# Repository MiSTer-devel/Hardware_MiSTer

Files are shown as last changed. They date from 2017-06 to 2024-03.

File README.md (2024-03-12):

# Hardware addons for MiSTer

### [I/O Board](https://github.com/MiSTer-devel/Hardware_MiSTer/tree/master/Addons/IOBoard), [AV Board](https://github.com/MiSTer-devel/Hardware_MiSTer/tree/master/Addons/AVBoard), 
I/O Board provides digital audio output, buttons, LEDs, user port, and VGA connector. It also supports secondary SDRAM (experimental).
With additional AV Board it adds VGA and analog audio output (but loses secondary SDRAM feature). I/O Board also provides external buttons and LEDs connectors for easier integration in various cases.

### [RTC daughter board](https://github.com/MiSTer-devel/Hardware_MiSTer/tree/master/Addons/RTC)
This board provides real time clock. It's plugged into LTC connector.

### [SDR SDRAM daughter board](https://github.com/MiSTer-devel/Hardware_MiSTer/tree/master/Addons/SDRAM_xsds)
This board provides 128MB of SDR SDRAM memory for cores requiring a large (>512KB) memory. Although DE10-nano has DDR3 RAM, it has big
latency and cannot fit into timings of retro EDO DRAM. So, if core quires precise memory timings, then DDR3 cannot be used.
Although some cores aren't requiring this board, still many cores need it.
Thus **SDRAM board is required**.

### [USB Hub daughter board](https://github.com/MiSTer-devel/Hardware_MiSTer/tree/master/Addons/USBHub)
This board provides 7-port USB hub for convenient devices connections. This is optional but recommended board.

### [MT32-Pi board](https://github.com/MiSTer-devel/Hardware_MiSTer/tree/master/Addons/MT32PiHat)
This boards adds external MIDI emulation plugged into user port. [Smaller version](https://github.com/MiSTer-devel/Hardware_MiSTer/tree/master/Addons/MT32PiHat_LT) is also available.

### [PiTop boards](https://github.com/MiSTer-devel/Hardware_MiSTer/tree/master/Addons)
The set of boards with PiTop in name are made to fit MiSTer into Pi-Top case. Note: it's for Pi-Top v1(original) case only. Pi-Top v2 case has completely different placements and conections and therefore is not compatible.

## Notes
You need to use Altium Designer v21.0 (or later) in order to view the source files. For convenience, [gerber files (*.zip)](https://github.com/MiSTer-devel/Hardware_MiSTer/tree/master/releases) are also included
and ready to submit to PCB manufacturer.

Some quick notes:
* **There are no notches/dents on 40pin connectors, so pay attention how you plug the daughter boards!** It's easy to plug it backward or shifted - **this may damage DE10-nano board**. Make sure PIN1 on one board is matched to PIN1 on other board. You may refer to pictures in images directory.
* It's preferred to order 1.6mm PCB thickness. I've tried 0.8mm and found no improvements in any aspect.
Thinner PCB are harder to handle and more fragile.
* SDRAM uses AS4C32M16SB-7TCN (64MB chip). Use [Memtest](https://github.com/MiSTer-devel/MemTest_MiSTer/tree/master/releases) utility to check the quality of SDRAM board.
* Every board has PDF file with schematic and PCB outlook, so you don't need any special application if you are not going to edit the files.
* Some images of boards can be found [here](https://github.com/MiSTer-devel/Hardware_MiSTer/tree/master/images)

### Options for PCB ordering:
* Board type: Single pieces
* Different Design in Panel: 1
* Quantity: usually 10. See the final price after change the quantity.
* 2/4 layers
* Material: any FR-4
* Thickness: 1.6mm
* Solder mask/Silkscreen colors: any you like if price the same.
* Min Track/Spacing: 6/6mil or less
* Min Hole Size: 0.3mm or less
* Via Process: Tenting vias
* Gold fingers: No
* Finished Copper: 1oz or more
* Surface Finish - HASL with lead. Some manufacturers provide ENIG (immersion gold) for free, but i don't suggest it as it's harder to solder than HASL (pre-soldered finish). "With lead" means lower soldering temperature. "Lead free" will require higher temperature for soldering.

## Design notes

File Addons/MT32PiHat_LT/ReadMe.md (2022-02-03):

# MT32-pi Lite boards set

* MT32Pi_lite - simplified MT32-pi board for Raspberry PI Zero 2
* MT32Pi_lite_Top - single sided aluminum 1.6mm PCB used as heat sink. This board needs spacers about ~1.5mm for screws. It needs thermal tape of 3mm thickness for main chip.
* MT32Pi_lite_Top_Cut - same as above but with cut places to mount it on top without spacers. It needs 2mm thick thermal tape.

As an option: you may mount both MT32Pi_lite_Top_Cut and MT32Pi_lite_Top, so Cut version will be used as a spacer and additional heat dissipation.

MT32Pi_lite board is soldered directly to RPI with short pins without connector. No need to solder all 34 pins. Soldering outlined pins is enough.

Whole pancake is plugged directly into USER I/O port as a side cart.

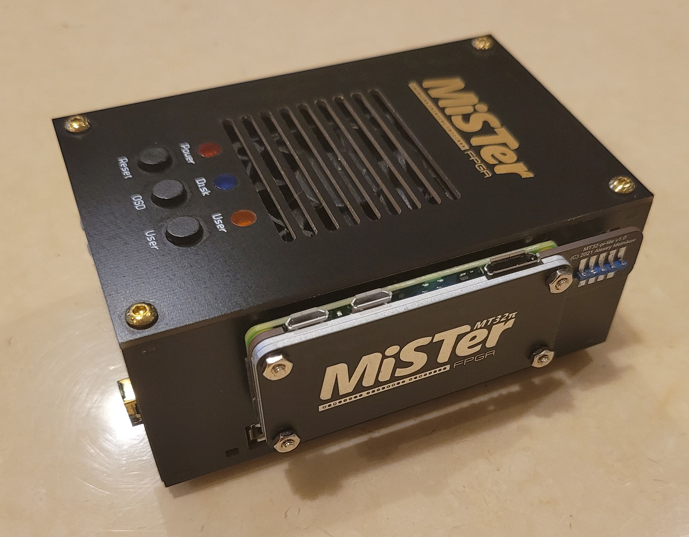
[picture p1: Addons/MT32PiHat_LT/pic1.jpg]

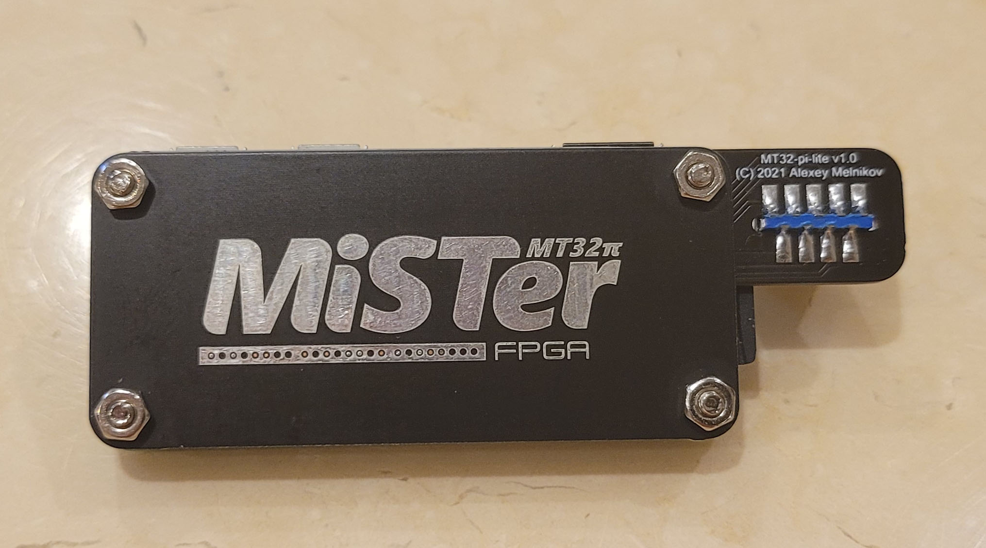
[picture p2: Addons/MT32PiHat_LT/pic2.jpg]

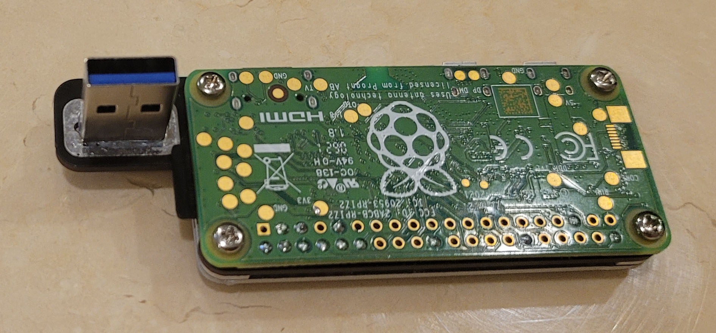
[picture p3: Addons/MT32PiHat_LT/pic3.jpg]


It needs a special USB3.0 connector:
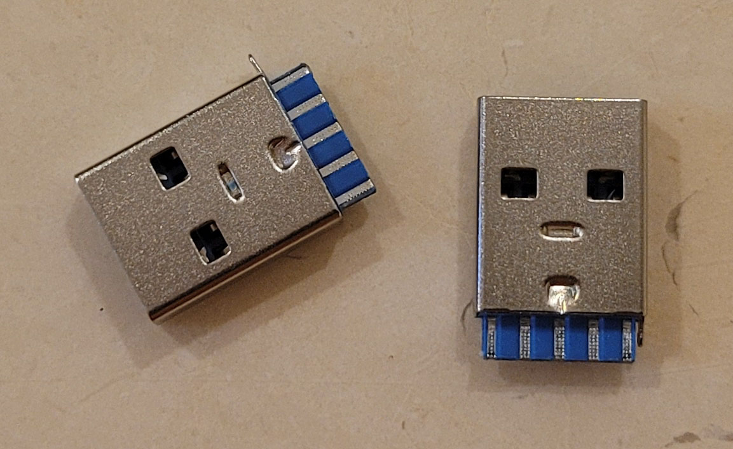
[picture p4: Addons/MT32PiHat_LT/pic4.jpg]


It can be found on Aliexpress and Amazon.

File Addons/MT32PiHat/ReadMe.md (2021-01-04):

# MT32-pi interface board

There are several simplified ways to connect MT32-pi without board at all. LCD and Buttons aren't required. 
You can see LCD overlay on MiSTer screen and change the mode from OSD. So basically you can wire USB-A connector to 40pin Raspberry Pi connector.

### Connection options:
* Basic MIDI connection: USB 2.0 connector is enough in this mode. Connect GND, VCC and TXD pins only. Since you cannot see LCD on MiSTer in this mode and cannot control MT32-pi, it's better to have LCD on device and buttons to control. In this mode you can connect basically any MIDI sequencer (not only MT32-pi).
* Audio-less connection. You need to connect GND, VCC, TXD, SDA, SCL pins. In this mode you will see LCD overlay and can control MT32-pi from OSD. Audio won't be mixed in MiSTer so you will need to use either I2S DAC on MT32-pi or 3.5mm jack on Raspberry Pi.
* You can use Main board but solder only 40pin connector and one USB. Useful for embedded designs.

### Notes
* There are 2 types of USB-A <-> USB-A. Straight one with all wires connected the same way on both sides. Crossed one where TX wires from one end connected to RX wires. No special notes required for crossed cables, they are pretty common and compatible with all MiSTer I/O boards. With straight cable you need a recent version of I/O board where IO6 pin is available and configured as IO pin (not 3.3V supply) otherwise 3.3V will go to output RPi pin. This may dammage the RPi. Resistor (R1) with 100 Ohm is used on board to avoid this colission and prevent RPi from damage.

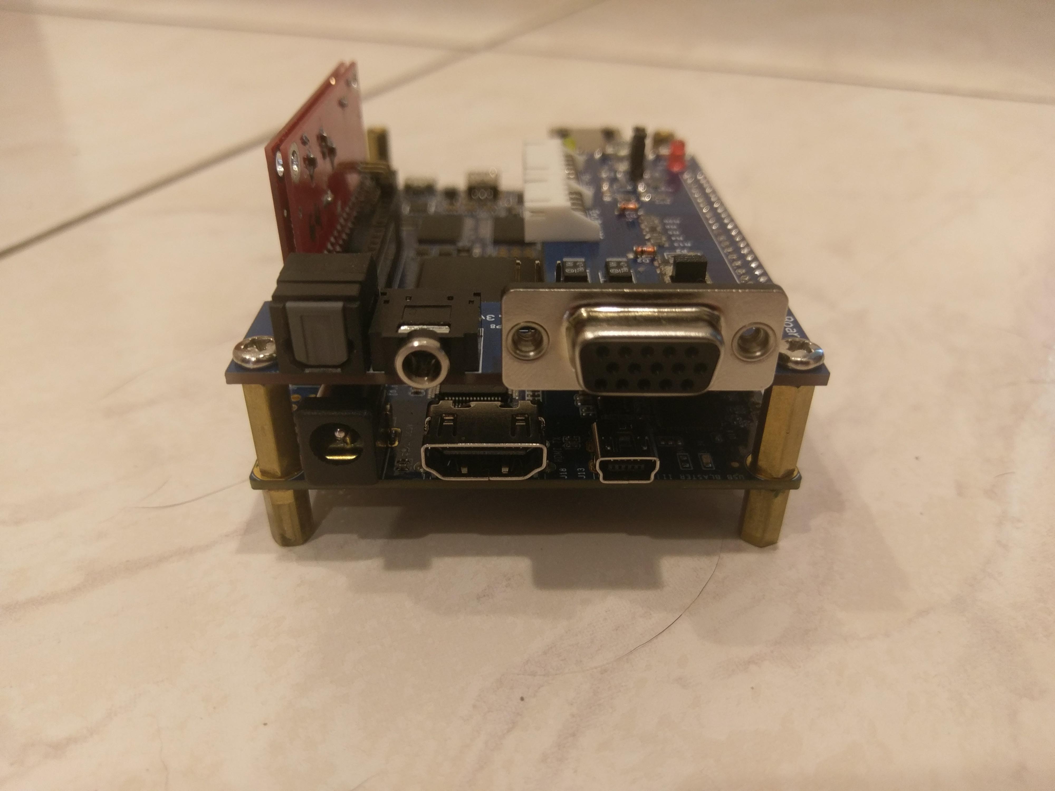
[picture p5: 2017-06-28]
images/MiSTer_2.jpg

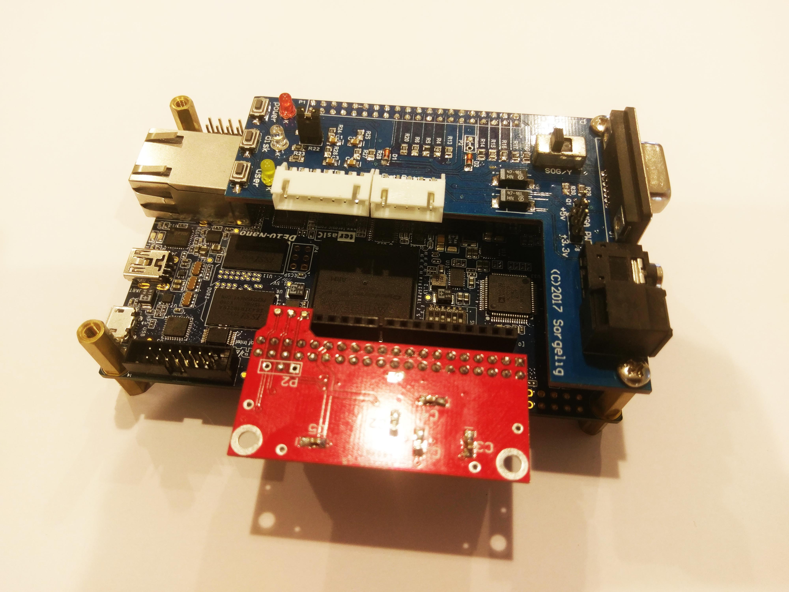
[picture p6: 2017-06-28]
images/MiSTer_SDRAM_horiz.jpg

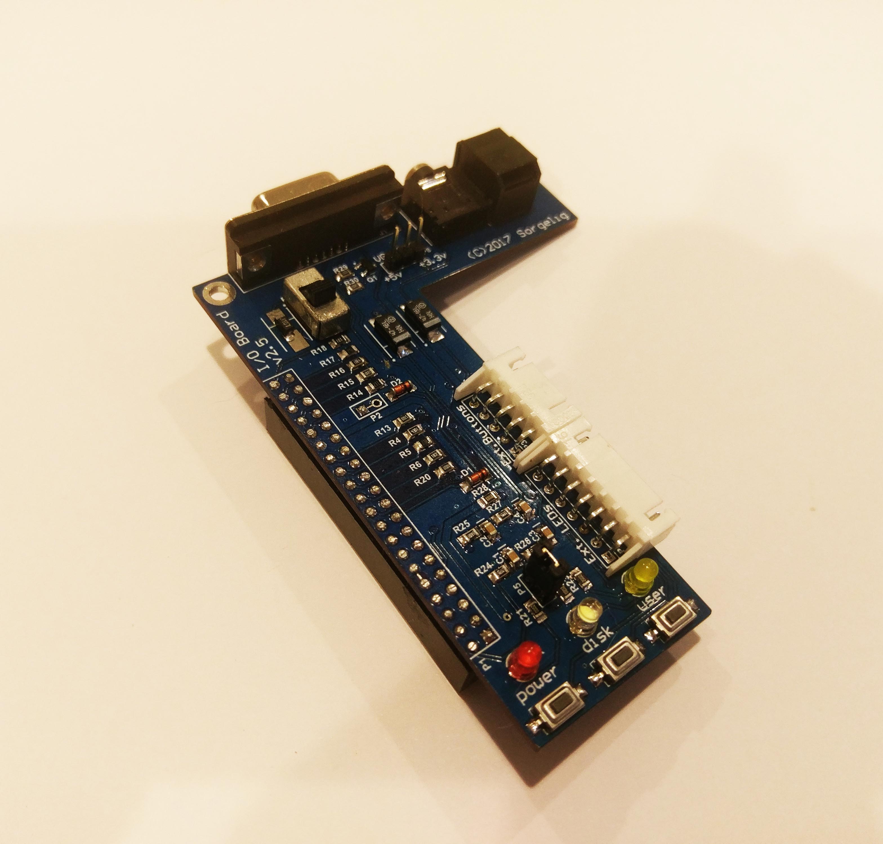
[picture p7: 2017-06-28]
images/IOBoard.jpg

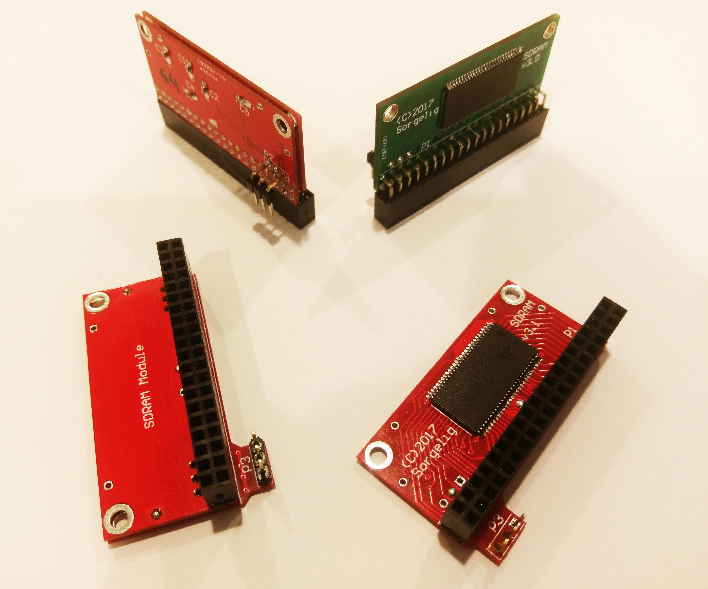
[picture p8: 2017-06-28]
images/SDRAM_board.jpg

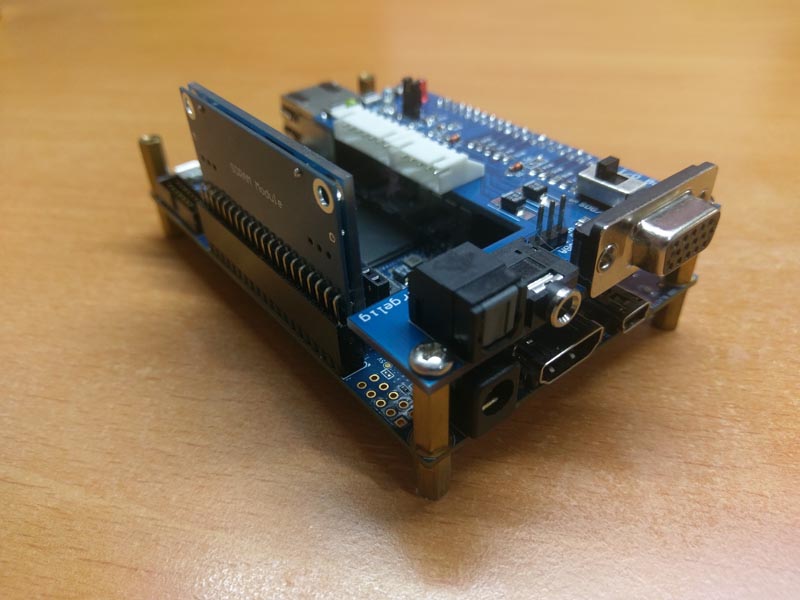
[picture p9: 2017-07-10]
images/MiSTer_AIO_SDRAM.jpg

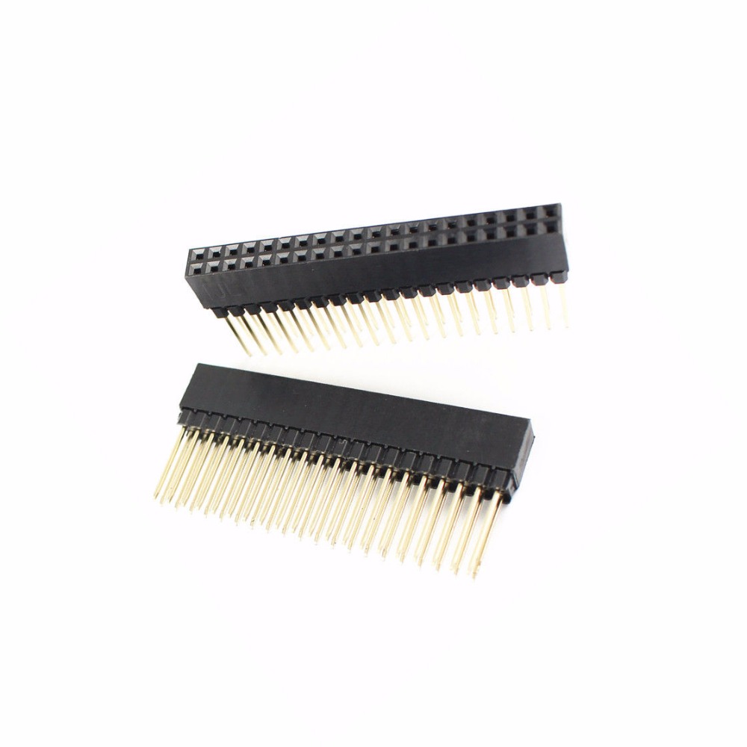
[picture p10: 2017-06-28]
images/header_2.54mm_Pitch-2x20_Pin-Female-Double_Row-Long_Pin.jpg

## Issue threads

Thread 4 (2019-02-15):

IO Board ESD Protection

zerohimself, 2019-02-15:
So, last week I damaged the FPGA on my DE10 board by accidently supplying a ESD shock to the button housing of the OSD menu on the IO board. The shock killed both GPIO pins for the OSD and USER buttons. I was using the IO board 5.5

I'm wonder if there is any protection that we can put in, maybe a diode somewhere?
Maybe this is a user issue, as we take that risk by using a bare PCB not in a case, but I figured I should report the issue and at least make a suggestion for someone who is more knowledgeable than me.

sorgelig, 2019-02-15:
I don't think it's possible to do anything against it. If you got high static charge on your body due to specific wear or something on surface where you walk, then discharge will be too high to protect 3V electronic device.
You need the case where buttons will be protected by thick plastic.
It's better to find the source of charge, put some grounded line which you will touch before touching electronic devices.

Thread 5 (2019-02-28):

'Order the boards' link leads to no project on PCBWay

dine909, 2019-02-28:
The embedded hyperlink in README.md leads to a dead-end.

https://www.pcbway.com/project/member/shareproject/?bmbid=43024

sorgelig, 2019-02-28:
PCBWay changed the link.
I've fixed it.
Thanks for info!

Closed 2019-02-28.

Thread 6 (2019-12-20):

problem with via tenting with SDRAM XSD v2.5

thioroup8, 2019-12-20:
Hi

I recently contact JLCPCB service to produce PCBs for SDRAM XSD v2.5. I used this gerber file: https://github.com/MiSTer-devel/Hardware_MiSTer/blob/master/releases/sdram_xsd_2.5.zip

Unfortunately, they sent me an answer containing question and I am unable to reply to them because of lack of knowledge.
Please find below a copy of their message.

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

Please help me to write appropriate answer to JLCPCB service.

Thank you for your attention.

sorgelig, 2019-12-20:
Time after time JLCPCB start to send stupid questions. This gerber file made many times by them without any questions.
Here also quite stupid ask from them. It's obvious the vias on pads are opened while without pads they are tented. 2 columns of holes in the middles are holes for THT connector, not vias.
Tell them to transfer approval to other more professional person.

thioroup8, 2019-12-20:
Thank you so much for your quick reply.
I already ordered all electronic parts from mouser and I was afraid to be unable to solder my own PCB due to JLCPCB manufacturer :(
I hope they understand my answer I will send to them following your instructions.
I understand it is not an issue in your design and so sorry to place this message in the wrong place...

thioroup8, 2019-12-20:
oups I clicked on wrong button.

thioroup8, 2020-07-13:
Hi

I am back again with my first try to solder a SDRAM board for my MiSTer.
Sadly I have some issues :( My memory board is not recognized by memtest utility.
So, I double check with my microscope and my multimeter. All seems correct.
So, I check another PCB without any component solder on it.
My multimeter detects unexpected connections: I mean, I am surprised to find thoses connections because I do not see them on gerber files. Please have a look on attached picture: unexpected connections in red.

What do you think about thoses connections? Is there any issue during PCB manufacturing?
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

sorgelig, 2020-07-13:
I don't see what unexpected there. GND to GND, VCC to VCC. Looks fine to me. Board has 4 layers, not 2.
I can't tell about manufacturing problem - it depends on specific manufacturer.

thioroup8, 2020-07-13:
On U2 chip, pin 54 is VSS
On U1 chip, pin 37 is CKE and pin 28 is VSS
So I do not understand "GND to GND"?
By simply looking at GTL, G1, G2 and GBL, it is difficult for me to deduce from these 4 gerber files the existence of those 3 connections (in red). I probably misunderstand gerber files: I need to improve my knowledge on this topic.

My SDRAM board is faulty and I do not know why:
- bad solders
- pcb issue
- component faulty
- ...

sorgelig, 2020-07-13:
VCC - is power, 3.3V
VSS - is GND.
CKE is connected to VCC - correct.
Even on your pic you clearly can see VSS pins are connected to ground.
You can check connections using schematics.
I don't have more files than i upload.

thioroup8, 2020-07-13:
Well
I made a lot of checks on an empty PCB and I think PCBs are correct.
I suspect I used an excessive soldering temperature of 350 °C and I killed one or several components because datasheets recommend a temperature between 235 °C and 260 °C.
Stupid mistake to learn :(

david-cash, 2024-07-10:
I already ordered all electronic parts from [OVAGA](https://www.ovaga.com/) and I was afraid to be unable to solder my own PCB due to JLCPCB manufacturer :(

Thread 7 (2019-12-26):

Q: Is it possible to use only one bank of the SDRAM XSD v2.5

vidarw, 2019-12-26:
Hi,
Thanks to everyone for designing and creating this well documented DYI-system.

I just realized the relatively high prices of the 512M Alliance Memory SD modules.
Is it possible to mount only one chip in the dual PCB and add the second memory chip at a later time?

sorgelig, 2019-12-26:
You can try. It may have slightly different timings and some cores may misbehave.

Closed 2022-11-27.

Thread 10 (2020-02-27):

The MiSTer I/O board does not output the proper voltages on the DB15 connector to allow for automated AV features over SCART

mathieulh, 2020-02-27:
The I/O board should be revised to add voltage to SCART PINs 8; 18 and 16
so it gets on spec and allows for automated AV selection

This would mean using unused pins on the DB15 connector for voltages and modifying the MiST cables.

This would allow automated AV features (assuming you switch to an updated MiST SCART cable) as per official SCART specifications

This way MiSTer could:
* Automatically turn on your TV
* Automatically switch your TV set to the AV channel on sets that support it (most sold in Europe since the mid 90s)
* Force force the use of specific signals over the same RGB cable (for instance switch from RGB to composite without changing the cable)
* Force 4:3 or Widescren aspects ratio (should someone ever need that)

More details regarding those specifications and features are available here:

http://forum.arcadecontrols.com/index.php/topic,77370.msg806492.html#msg806492

and

http://forum.arcadecontrols.com/index.php/topic,77370.msg830465.html#msg830465

sorgelig, 2020-02-27:
Sorry, it's out of MiSTer scope.
VGA connector has option "VGA_PWR through pin 9. It may output 3.3V or 5V. If you want other voltages, then you need to add external step-up DC-DC converter.

Closed 2022-11-27.

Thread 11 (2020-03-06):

The MiSTer I/O board has serious issues with brightness levels when connected to a VGA monitor

mathieulh, 2020-03-06:
The MiSTer I/O board has serious issues with brightness levels when connected to a VGA monitor

When I plug a shilded coaxial VGA cable (ie, the best quality you can get) to the dsub 15 output from the IO board to my CRT VGA monitors (I tested 2 different ones) the brightness is very dim
almost as if you did not have adequate impedance or power output.

If I connect the exact same cable (and monitors) over direct video using the same MiSTer configuration the image looks great with no brightness issues whatsoever.

This appears to be hardware issue related to the I/O board itself.

sorgelig, 2020-03-07:
It must be very specific to your setup/monitor.
Usually VGA output provides good video. I have tried many monitors - no problem with brightness. Anyway, if more strong signal is needed then it will require additional amplifiers. It won't happen in I/O board as there is no place on board and 5V power will not be enough for analog amplifiers.
Use Direct Video - it provides more bits per color and better audio DAC.

mathieulh, 2020-03-07:
Hum... I am having the issue on both my CRT monitors, a Sony Trinitron CPD-200GST and a Compaq P1220 (Mitsubishi Diamondpro 2060U rebrand), the only thing I have not tried yet is swapping the I/O board as I do not own another at this point. I also tried different cables.

sorgelig, 2020-03-07:
May be wrong video DAC resistors are used on I/O board.

twinkytwonka, 2020-06-14:
> Hum... I am having the issue on both my CRT monitors, a Sony Trinitron CPD-200GST and a Compaq P1220 (Mitsubishi Diamondpro 2060U rebrand), the only thing I have not tried yet is swapping the I/O board as I do not own another at this point. I also tried different cables.

If it's a V6 or 6.1 io board then what resistor array pairs did you use? Your choice has a significant effect on brightness levels . If you're using a 5.7 board then double check components with the schematic

Closed 2022-11-27.

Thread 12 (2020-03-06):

Pulsing LEDs on powerup, nothing else happening!

Galbi3000, 2020-03-06:
I've not used my MiSTer for a few months (been busy PC gaming instead of retro). It's just been sitting on my desk in all the time unpowered with the same SD card in since the last time I used it, not taken it out to update or make any changes.
Today I decided to boot it up again as I got some new ROMS I wanted to try out, I switched the MiSTer on and nothing happens. Well, nothing that should happen.

What I am getting instead of the MiSTer bootup sequence on my TV is no signal and the addon board pulsing the red and yellow LEDs (labled POWER and USER respectively). The smaller red LED is just on.
Under the addon IO board I see the green LEDs beside the ethernet port also pulsing the first and fifth LEDs.

What is going on? Like I said, the last time I booted it up it worked fine and it's just been sitting there unpowered until today.

Here is a GIF to show what the LEDs are doing:

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

sorgelig, 2020-03-06:
Please use forum for discussion. Github is for specific issues.

Galbi3000, 2020-03-07:
How is this not an issue? The thing is not working and I do not know why!

sorgelig, 2020-03-07:
LEDs flashing is correct.
post your problem here:  http://www.atari-forum.com/viewtopic.php?f=117&t=34710

Galbi3000, 2020-03-07:
Well, if the LEDs flashing is correct, that still leaves the fact I have a black screen on my TV, there is still an issue of the device not functioning as it should! It is in my description of what is wrong and in the issue title "nothing else happening!". You are always so quick to just dismiss an issue it seems. I have started actively pointing this out on YouTube videos talking about the MiSTer, an otherwise good product let down by poor support. Good bye.

sorgelig, 2020-03-08:
Ask those where you've bought the product. I didn't sell you anything.
This is my hobby and i do this for free.
Please leave and don't come back again!

RetroShopPT, 2020-03-08:
> Well, if the LEDs flashing is correct, that still leaves the fact I have a black screen on my TV, there is still an issue of the device not functioning as it should! It is in my description of what is wrong and in the issue title "nothing else happening!". You are always so quick to just dismiss an issue it seems. I have started actively pointing this out on YouTube videos talking about the MiSTer, an otherwise good product let down by poor support. Good bye.

Hi, look like a bad sdcard update and not hardware issue. Anyway, from photo, look like a board sold by me, and if you have any problem with hardware, just send me a message on Facebook or on my site.

Closed 2020-03-07.

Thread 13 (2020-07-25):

MiSTer I/O board detection? Custom VGA resistor ladder detects no signal on pins

JohnBFrm, 2020-07-25:
Hi,

I'm working on building my own resistor ladder for outputting various analog video signals as per the design of the "VGA" output (knowing it's not an actual VGA output) on the IO boards.

However, I am unable to measure a signal on the pins. It seems to just be a fixed voltage, flatlining my oscilloscope.

Does MiSTer require some sort of pin pull-up or down in order to detect that an IO board is attached and use the GPIO pins for their intended function?

JohnBFrm, 2020-07-26:
As this  is not an issue with a board per se, I'm going to close the issue with the following comment:

It's not explicitly stated in the board documentation, but pin 10 needs to be connected to ground, works fine with pin 12 and pin 30 as per the IO board schematics. This makes sure analog video output is enabled.

Closed 2020-07-26.

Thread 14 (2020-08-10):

Supply a proper BOM and/or Altium files in ASCII format

fade0ff, 2020-08-10:
The Wiki typically describes old versions of most addon boards and there doesn't seem to be a BOM, so it's a bit of a drag to find out which exact components are needed. Also it would help if the design files (schematic/layout) would be stored in Altium ASCII format so there would be at least a chance that more affordable EDA tools could import them.

iCityWork, 2020-12-02:
I second this! I would love to see a BOM for all the latest versions since I have a Mac I can not use the design software this was done in.

birdybro, 2021-04-14:
Third'ed. Definitely would love to see actual general BOM's for these pieces of hardware someday.

DanielBarie, 2021-09-28:
Upvote!

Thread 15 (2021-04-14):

Request: STEP or STL files for each board for easier CAD design of accessories.

birdybro, 2021-04-14:
I would love if I could load a STEP or STL file of the boards and their components in one of the many free CAD programs out there to begin designing 3d printed cases and accessories. Unfortunately this currently requires extremely expensive premium software to even export these, and there are tools online like altium2kicad but they are not very functional. I realize that moving to open source PCB design tools is undesirable however can some of the paywall-locked features like STEP/STL export from the Altium format be at least provided for us here?

Thank you!

KhalidHisham, 2021-04-19:
you mean like this?
[sdram_xsd 3D-model.zip](https://github.com/MiSTer-devel/Hardware_MiSTer/files/6337187/sdram_xsd.3D-model.zip)

I am new to gethub so I am not sure how to upload the files to the repo otherwise I can help.

\K

KhalidHisham, 2021-04-20:
Thanks, I will do it as soon as I can.
Perhaps it will be cleaner to put all the step files in one folder?

birdybro, 2021-04-20:
Maybe. I usually try to match the folder structure that the repository
already has to make it more agreeable to the maintainer of that repo.

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

KhalidHisham, 2021-04-20:
Ok so I generated everything but it seems i can't add the files using GitHub desktop. for some reason no changes are shown when I simply put the files in their respective places. Is there a way to fix?

birdybro, 2021-04-21:
Looks like it worked!

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

Next you have to submit the pull request.

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

:)

KhalidHisham, 2021-04-21:
That was quite detailed,
Thanks :)

birdybro, 2021-04-21:
Glad to help. Welcome to GitHub! 👍🏻

KhalidHisham, 2021-04-22:
Thank you. It is done now.

I found out the problem I had with the gitHub desktop. It seems that the all STEP files are placed on ignore list in the repository configuration. So I decided to zip all the files before adding them to their respective folders and it worked.

sorgelig, 2021-04-23:
it's on repo now

Closed 2021-04-23.

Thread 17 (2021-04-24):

SDRAM XSDS v2.9 decoupling issues

prrole, 2021-04-24:
Pin 37 CKE is decoupled, while pin 1&3 VCC share a capacitor.  I assume this is a routing mistake as all 3 pins are labeled VCC.

74LVC1G04 could probably benefit from a decoupling capacitor as well.

sorgelig, 2021-04-24:
pins 1&3 are very close to each other and have large polygon connected to both, so i don't think there will be any noticeable benefit for that.
Pin 37 has capacitor not as CKE but as distributed capacitance since it's far from other capacitors.
For LVC1G04 - probably can connect its VCC to upper polygon and share the cap nearby. I will think about it if i will update the design

Closed 2022-11-27.

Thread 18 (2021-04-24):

SDRAM XSDS v2.9 missing part number

prrole, 2021-04-24:
There is no part number for P1 2x20 SMD connector in schematics or pcb file.  The 3D model shows a connector that is not common or easy to source, so a part number/source is needed to build this board.

sorgelig, 2021-04-24:
Because it's common connector without specific part number.
you can find it on Aliexpress or eBay.
you may order this one:
http://www.townes.com.tw/product_detail/land-ctop-2/index.php?Product_SN=68153

Closed 2022-11-27.

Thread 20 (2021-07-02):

SDRAM XSDS v2.9 has a strange solder pad.

type78, 2021-07-02:
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

There's a strange small solder pad on v2.9 SDRAM PCB. (please see the picture I attached.)
Is it intended?  If it is, what's the purpse of this small pad?

sorgelig, 2021-07-02:
it's an option. You may opt out LDO and solder that pad with nearby pin together to get 3.3V from de10-nano

Closed 2021-07-02.

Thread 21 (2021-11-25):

Provide viewable static files without requiring software install

aeberbach, 2021-11-25:
It would be great to be able to look at a schematic without having to install PCB software. Altium?

aeberbach, 2021-11-25:
Found them in releases folder

Closed 2021-11-25.

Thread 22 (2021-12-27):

Help with usb board

sonik-br, 2021-12-27:
Hi,

My USB board is busted. The component over the U2a (NCP380LSNAJAAT1G) is burned and I can't find another to buy.
There's any equivalent component that will work?

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

sorgelig, 2021-12-28:
option #1: you may disable VBUS control, so you won't need this chip. USB devices will have permanent 5V supply from main power. Refer to schematics and notes there.
option #2: there are no equivalents. There is only version for uDFN6 case of the same chip which may hold slightly higher current than busted TSOP6 version.

sonik-br, 2021-12-28:
Thanks for the answer.

I'm a layman in electronics .

What's the purpose of VBUS? If I get it right, it's to power on/off the usb hub in sync with mister's main board?

For option 1 I can just bridge the JP3? JP1 too?
It will drain power from the mister's usb or from external psu?

sorgelig, 2021-12-29:
> What's the purpose of VBUS? If I get it right, it's to power on/off the usb hub in sync with mister's main board?

it allows USB host controller to turn power on/off of USB devices.

> For option 1 I can just bridge the JP3? JP1 too?

Short JP1. JP3 doesn't matter.

> It will drain power from the mister's usb or from external psu?

It will drain power from the same source as with VBUS control.

sonik-br, 2022-02-05:
My board is dead. Even without VBUS. Power works but no data.
I've got a new one :)

Closed 2022-02-05.

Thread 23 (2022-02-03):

Solderless MT32Pi_Lite using pogo pins

tmznix, 2022-02-03:
Is it possible to modify this board to use pogo pins instead of soldering ?

Something like this: (examples)

https://thepihut.com/products/pogo-a-go-go-solderless-gpio-pogo-pins

Or this:
https://pinout.xyz/pinout/zero4u#

And the last one ( I promise :) )
https://www.kickstarter.com/projects/pico-learber-board/notixed-turn-your-pi-zero-to-usb-device

Cheers!

sorgelig, 2022-02-04:
From PCB point of view, no modifications are need. Since pins are too high, you will need to place MT32Pi_Lite under the RPi so USB3.0 plug will be able to fully inserted. Overall construction will be very thick and bulky. If you like this then use it. Original idea was to eliminate connectors and make construction as slim as possible.

rataweb, 2022-03-02:
Hi,
It's a good idea.
Please, Could you upload Altium pcb files in ASCII format? I'm using Eagle and it's the only way to import Altium files. I'll try to modify by myself.

Many thanks
Shark

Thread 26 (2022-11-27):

[Feature Request] Hardware_MiSTer/io_brd_6.2 with dedicated DAC circuit

ArcadeTV, 2022-11-27:
I use io_brd_6.1 on my MiSTer Setup with [this external DAC](https://amzn.eu/d/gATQUuJ) for better audio.

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

To minimize the need for cables and power supplies I had the idea to merge the DAC's circuit into the io board. Before I start creating a pcb for modding io_brd_6.1 I wanted to ask if this may eventually be added to io_brd_6.2. By merging the circuit into the io brd R6 (75R), the AMS1117 regultor and its components and the coax-parts become obsolete. [Here](https://www.dropbox.com/scl/fo/4myo1c3tk06i6u13dm5p3/h?dl=0&rlkey=h2cjf12vrrlcghgtq57sm88s8) is my Dropbox folder containing my scans and datasheets.

I don't know or have Altium, so I'd like to know if it would be possible to export the io_brd_6.1 to eagle or if the DAC circuit could be included in the next version of the pcb, maybe with an addional switch to toggle between native audio and DAC output.

If this may be rejected, I plan to create an addon-pcb that may be positioned here and using the existing pads:

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

---

For prerequisites I stripped the DAC and drew its schematic:

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

sorgelig, 2022-11-27:
I suggest to make an addon board using I2S header from I/O Board, so it will follow modular structure of MiSTer. I use it as well for some my embedded MiSTers. It will eliminate CS8416 as well. Just need to find I2S DAC which can work without MCLK. Current I/O Board has no free space for such circuit, so embedding it to board will require a denser routing and smaller components which i don't want to do. I want to make it DIY friendly.

If you will do an addon board then may be it would be better to make a tiny board which will plug directly to that i2s connector and use 3.5mm jack on top of existing one. Just thoughts..

Thinking more about this: most modern high-end amplifiers have either optical or coaxial input which is anyway better than analog. Your board is mostly for integrating into some arcade cabinet where such amplifier is not available. Thus using original external converter should be fine already. If your amplifier has no digital input, then you may place this converter near your amplifier and hide somewhere there, so for MiSTer you will need only thin optical cable.
HDMI btw, has no such issue as it delivers digital audio. In direct video mode you can use HDMI-VGA converter with audio output.
So, basically there are many options for better audio are available.

sorgelig, 2022-11-27:
btw, i even not sure if integrated converter on I/O board will have enough noise over power/gnd isolation. Analog part should be well isolated which separate board with separate power supply does.

sorgelig, 2022-11-27:
not sure your original intention of using this converter.
In case if you use HDMI output and simply want to connect some small stereo speakers, then this converter probably will be more suitable:
https://www.amazon.com/Optical-ROOFULL-Extractor-Splitter-Converter/dp/B01LL5RI3Y

ArcadeTV, 2022-11-27:
Thank you very much for taking the time to answer, this is very much appreciated.
The motivation for this is to NOT have extra external hardware and power supply. The device works great, but I'd love to have it inside the MiSTer. I'm not a professional, so any hint about best-practise and isolation is great. Maybe additional coils or EMI-filters could cut the noise?

This is what I had in mind, piggyback an add-on-pcb under the I2S and VGA-PWR headers, so they can be installed back and stay functional. For L and R audio-lines, either the traces could be cut or C11 and C12 could be removed and DAC-output connected to their pads.

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

This is a mockup of what it could look like, all the parts are already present.
This is not as modular as I'd love to make it, but if it works it would be beneficial for me.
Since I use CRT's only, I never connect HDMI.

retrorepair, 2022-11-28:
It seems to me all you would need there is a pin header where you have the pads currently and maybe a dip switch/jumper block to select built in audio and I2S on the jack output. The wouldn't impact the IO board's design at all and then everyone's happy?

It has to be said, using those cheap Amazon DACs gives a vastly superior analog audio output than what's built in. I'm not much of an audiophile but it's a huge step up. Eradicates the pops on core change too.

ArcadeTV, 2022-11-28:
Indeed, that would solve the problem. I did some routing in the meantime.

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

retrorepair, 2022-11-28:
Looking good.

Rather than cut the board traces, you could always remove the two large caps under the IO and hijack the audio output from the two vias leading to them. I think your board would need to extend to the far one though and I believe your caps/resistor may currently be in the way of the other.

I always find soldering to cut traces a bit hacky and often leads to poor connections.

The other alternative would be to cut the two traces leading to the I2C header before then hit RN17 and the top side traces to the GPIO, then either run jumper wires from the I2C to the audio jack or maybe even a nice QSB to keep it somewhat tidy? Hijacking those now spare pins of course with your own audio outputs.

ArcadeTV, 2022-11-28:
> Rather than cut the board traces, you could always remove the two large caps under the IO and hijack the audio
Yes, I already wrote that C11 and C12 could be used for that.

> I think your board would need to extend to the far one though and I believe your caps/resistor may currently be in the way of the other.
I'm afraid there's zero space left to move anything around, so maybe the wires need to go from top to bottom - which would be ok when using a shileded cable

> You plan to add it as open source in the MiSTer GitHub?
I didn't plan ahead tbh, but I will create a repo with full source files once it's tested. I'm afraid, as sorgelig pointed out, there may be issues with ground loops and noise when run off the internal MiSTer power, so maybe coils and emi filters have to be added, but I have no experience with that.

n67t1cq, 2022-11-29:
It is good to implement PCM51002 into IOBOARD.

I've made i2s addon board for 6.1 last year. It works good.
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

ArcadeTV, 2022-11-29:
> PCM5102a

That's really cool and I wish I had know this existested before I started ;-)
Where can I get one? I've read that this IC is programmable - would you share some insights how it works?

ArcadeTV, 2022-12-01:
@n67t1cq could you share some insights?
Is it for sale or maybe even open source?

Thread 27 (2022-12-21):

Deprecate Secondary SD Card

thehughhefner, 2022-12-21:
Hi Sorg,
I think it is time to deprecate the secondary sd card. Today, it is not mandatory to use it, and cores that make use of it have other ways of loading ROMs. Wouldn't it be better to use another component instead? (Such as 24 bit rgb). It will also remove any user errors where they will be confused of the use of secondary sd card

sorgelig, 2022-12-21:
Actually analog output is kind of deprecate. Use direct video for 24bit VGA/TV output. Secondary GPIO connector will be re-purposed for extension to get more powerful CPU emulation (and may be other things).

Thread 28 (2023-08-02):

MT32Pi Top Gerbers broken

Shadowtrance, 2023-08-02:
Title.
It seems the gerbers for the MT32Pi Top piece are broken in some way.
When imported to jlcpcb this is the result (1).
And if you select the top or bottom after initial loading (2) you only see a corner of the pcb with a hole that isn't drilled out and not much else (3).
The main base board that actually matters _appears_ to be fine though _i think_.

1. 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

2. 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

3. 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

sorgelig, 2023-08-02:
Their online gerber viewer is very buggy. Don't verify correctness there.

Shadowtrance, 2023-08-02:
Well it wasn't just jlcpcb. I checked it in kicad gerber viewer and some others online all with slightly different but weird results.
I thought I was going a little crazy... hopefully not. haha Main appears to be fine on JLC in 2d and 3d views, but then different in kicad gerber viewer. So I don't know what to believe...

Top 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

Main 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

sorgelig, 2023-08-02:
It's relative/absolute coordinate mistreat between drill and gerber. Don't worry. JLCPCB stuff will correct it. All boards i release I've ordered from JLCPCB already.

Shadowtrance, 2023-08-16:
Ok yeah i have no idea what weirdness was happening with every gerber preview i looked at but i ordered them anyway and they can in today perfectly fine and not some weird cutout like the jlc preview showed for the top.
All good and thanks for creating the addons! :)

Closed 2023-08-16.

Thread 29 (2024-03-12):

Toslink audio out

lucaslbds, 2024-03-12:
My Mister's toslink audio out doesnt work in my dac with correct cables.

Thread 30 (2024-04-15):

fix suggestion: remove possibility of wrong pin insert alignment

goofyseeker311, 2024-04-15:
if there would be a socket, that would fit with the de10-nano in only one way,
or that there would be a protection circuit in case of wrong pins, there would be
no way to brick any of the boards. just saying as feedback as an user.
if you can break it, you will break it, like with the sdram board pin misalignment, into wrong pins.

sorgelig, 2024-04-15:
If de10-nano would use shrouded connector like IDE HDD, then it would exclude wrong insertion. But DE10-nano uses naked pin header, so there is no way to prevent it. Adding protection circuit is impossible too.

When you buy a TV or phone, you buy it fully assembled. So do it with MiSTer too. Leave DIY option to professional people.

goofyseeker311, 2024-04-15:
I'm a professional electrical engineer, and of course all is possible. there is a way to make a suitable socket.
but you do you.

sorgelig, 2024-04-16:
I don't sell anything, don't you know? I don't even get any revenue from sales besides some sellers donate sometimes to me.
This is hobby and community project.
Generally speaking it's supposed that you buy all components and solder all addon boards yourself bearing all risks on yourself.
If you buy a Raspberry Pi or Arduino boards and then randomly connect the pins, then any damage you made by that is not covered by board manufacturer. Same with MiSTer.

As a community/hobby project it's developing with help from people wanting to share their improvements. Since you are professional (as you said), you may offer protection circuit or other improvements preventing wrong insertion.

goofyseeker311, 2024-04-16:
just bringing up potential fixes/improvements, if someone wants to incorporate them.

sorgelig, 2024-04-16:
It's easy to suggest and it costs nothing. Just make a prototype which suits everything you've said. Spend the time, money, nerves and so on.
Then come here to share everything here for free.
Agree?

goofyseeker311, 2024-04-16:
only half, its better to first state what the improvement is, so that anyone can do it, even if I would not be doing it.
then even I can do it, better have a good plan first, half the work, agree?

goofyseeker311, 2024-04-16:
about the being a "pro", I do hold an uni master/semi-phd in electronics/semiconductor/nano-tech.

goofyseeker311, 2024-04-16:
I dont like to be forced either.

this is how it works in the corporate world, where I would be a lead designer, not the implementer.
mostly being on the design requirements side of product process. but I could/can do it myself when I want to.

sorgelig, 2024-04-16:
And there is 5V pin on connector, and whatever signal it collided on wrong insertion, it will damage the board because SDRAM is 3.3V. Go to protect it ;)

goofyseeker311, 2024-04-16:
yes that 5V vs 3.3V is an issue, but it can be dealt with.

sorgelig, 2024-04-16:
> I would be a lead designer, not the implementer.

I see, lol :)

goofyseeker311, 2024-04-16:
I say this before even looking at the circuit design.
so how about the series resistor on all the data lines.

sorgelig, 2024-04-16:
> so how about the series resistor on all the data lines.

No problem. You can try it and report it here.

> or maybe just a voltage divider from 5v to 3.3v.
already added in recent SDRAM revisions. It has nothing to do with protection. Shifted insertion will put 5V on nearby signal.

goofyseeker311, 2024-04-16:
it has all to do with the data line protection, to prevent excessive current and voltage. its about mass current at 5v to actually burn stuff on wrong pin, not the 5v signal alone. it would not work with the 5v signal would it would not burn.

goofyseeker311, 2024-04-16:
yeah I would just put a resistive voltage divider on the data lines, even if it has high output impedance not matching the sdram chip impedance.

sorgelig, 2024-04-16:
couple more hours and you will say that current board design is fine.
Laziness is the strongest force!

goofyseeker311, 2024-04-16:
lol :)

goofyseeker311, 2024-04-16:
this is fine. lol.

Closed 2024-04-15.

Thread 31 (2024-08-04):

Please provide ODB++ Files for the Projects

djusHa, 2024-08-04:
Good Day,

Can you please provide odb++ files for the Projects?
This would be nice

sorgelig, 2024-08-05:
i have no idea what is odb++

djusHa, 2024-08-06:
it's an interchange file format like gerber, but a little bit newer.

https://en.wikipedia.org/wiki/ODB%2B%2B

sorgelig, 2024-08-07:
I provide only standard gerber file, sorry. This is enough to produce a PCB. If you want other formats then you need to find a converter or use my source files to produce what you need.

djusHa, 2024-08-08:
ok, thanks anyway.

Closed 2024-08-08.

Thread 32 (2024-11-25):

[Feature Request] Saturn 10-pin mini DIN AV port for the next official I/O board

thericeking, 2024-11-25:
Has any consideration been given to adding a Saturn 10-pin mini DIN AV port to the next official I/O board, similar to the MiSTerAddons (Porkshop Express) IO Direct board? Forgive my ignorance, but it looks like it would allow the option of dual RAM analog operation and HDMI, albeit not at the same time. It is still really nice having both options. I'm very curious to know what's your opinion on this. I apologize in advance if this has been requested and answered before, but I couldn't find any discussion about this on the Internet. Thank you in advance in taking the time to respond. Take care.

sorgelig, 2024-11-25:
It's just a connector. It won't give you dual-SDRAM and Analog output at the same time. MiSTer Addons I/O board has integrated HDMI->Analog converter - that's how it provides analog output. You can achieve the same by using external HDMI->Analog converter.
Saturn connector is less used than VGA connector and requires quite specific cable. MiSTer goal is to use as popular as possible connectors for easy connection. That's why I/O board uses VGA connector.

thericeking, 2024-12-09:
Thank you for taking the time to respond.

Closed 2024-12-10.

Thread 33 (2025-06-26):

Analog Audio Out Distortion

TheJesusFish, 2025-06-26:
**TL;DR: The stock designed 9.2 board (with io mezzanine) has an issue with audio out in some cores and some games. I haven't done a full barrage of testing, but it's very easy to hear in Keio Flying Squadron for the Mega CD. Further, it seems like this may be related to the vga_mode setting in the MiSTer.ini.**

As referenced [here](https://github.com/MiSTer-devel/MegaCD_MiSTer/issues/112#issuecomment-3002300641) and [here](https://github.com/MiSTer-devel/MegaCD_MiSTer/issues/114), there has been some weirdness with analog audio out on the 9.2 boards (we see folks bringing it up in the discord help channel as well).

I decided to buy a bunch of boards to test to see if we could get to the bottom of the bug. It turns out that this issue is **not** limited to the Mister Pi 9.2 board. I would imagine that is just the most prevalent IO board based on the stock 9.2 design, and that's why folks reporting the issue are more likely to be using it. I have included the recordings in a zip.

Testbed:
- de10 nano
- MiSTer Addons 128mb 3.0 SDRam
- Stable Mister and cores (all updated)
- Games stored on the SD card.
- Global Volume set to 5 bars

Keio Flying Squadron tests:
- IO 6.1 board and vga_mode=rgb (control): No distortion
- MiSTer Addons Analog Pro vga_mode=rgb (9.2 board - non-stock design): No distortion
- Retro Remake 9.2 Pro vga_mode=rgb (stock design): heavy distortion
- Legacy Pixels 9.2 Pro vga_mode=rgb (stock design): heavy distortion

Furthermore:
- Legacy Pixels 9.2 Pro vga_mode=svideo (stock design): no distortion
- Legacy Pixels 9.2 Pro vga_mode=ypbpr (stock design): light (no?) distortion

I'm happy to do further tests with other games that have reported problems, but this felt like a good jumping off point if you had any appetite to look at this.

[Sound Recordings.zip](https://github.com/user-attachments/files/20917774/Sound.Recordings.zip)

bootsector, 2025-06-26:
Taki boards are created as per specs and are very high quality as far as I can tell. My Taki 9.2 analog board has the same issues but they seem to get "fixed" if I play around with the vga_mode settings or use one of the "shifted" cores. I think that if those were related to hardware//quality issues then the issues would persist regardless?

Oh, an optical DAC solves the issue as well, so that's what I'm using for now.

TheJesusFish, 2025-06-26:
Luckily, the issue does not affect a lot of games. Based on what I have seen in the discord, it is almost entirely isolated to the Mega CD and PSX cores. And even then, a very limited amount of games.

As Boot mentioned, Robert built a shifted PSX core troubleshooting something else and that core happened to fix the sound distortion issue for the folks that were experiencing it. That build changed nothing audio wise, so Robert wasn’t sure why it suddenly fixed the issue (especially since timings were met during the build).

I’d be more than happy to send you both reference-based boards if you want to compare their construction to your designs. I didn’t mean to insinuate it’s a hardware issue. I only filed it here because it was related to the boards and not a singular core/game.

TheJesusFish, 2025-06-29:
Same everything (de10, power source, sd card, and wired controller). Only thing that changed was the IO Board.

sorgelig, 2025-07-01:
I have no distortion on my IO 9.2. Tested on USA version of Keio game.
So, it's weird why some boards have such distortion and only specific game... I have no idea, unfortunately.

paulb-nl, 2025-07-01:
Thanks for testing @sorgelig . You have `vga_mode=rgb` in ini?

TheJesusFish, 2025-07-01:
So strange.

I have tried those two boards in a couple of different DE10s and Mister Pi boards - all the same result (that’s why I finally made the issue because it felt like a smoking gun). I wonder if there is a way that folks are manufacturing these that differs from the boards you built. I haven’t tried the 9.2 board from UltimateMister or Misterfpga.co.uk yet - going to see if someone on the discord has them.

The recording I included above is with global volume at 5. I didn’t touch core volume, so that’s potentially another thing to check.

But, either way, the problem disappears when using a different seed to build both cores. I dunno if that means that there is an issue with the way both cores are written, or if the build is assembled down a certain path it triggers a hardware issue. Either way, it can be mitigated by changing the seed (everyone’s favorite solution :) ).

I thought for sure we had finally found a way to track this one down, though.

nekrondev, 2025-07-01:
For the context: my Mister Pi (turbo pack, batch 2 from December 2024) doesn't output the distorted analog audio TJF posted here. It seems to be random silicone lottery...

TheJesusFish, 2025-07-01:
> For the context: my Mister Pi (turbo pack, batch 2 from December 2024) doesn't output the distorted analog audio TJF posted here. It seems to be random silicone lottery...
>
> Edit: Wait, let me crosscheck if `vga_mode=rgb` is set (I didn't modify Takis default presets)... ok, not found in the `Mister.ini` but docs tell `vga_mode=rgb - Changes the VGA output to a rgb, ypbpr, svideo, cvbs. rgb is default.` I additionally added it and rebooted the device, but audio seems to be fine on my headphones.

I wouldn't use Taki's mister.ini - not sure what they have changed. Grab this one: https://github.com/MiSTer-devel/Main_MiSTer/blob/master/MiSTer.ini and test again if you have a chance.

AtelierBleu, 2025-07-01:
I’ve attached uncompressed, 24-bit 44.1khz stereo audio recordings of the Keio intro with vga_mode=svideo (clean) and vga_mode=rgb (dirty). I also noticed that the loud audio pops appear in the left and right channels at different times rather than simultaneously.

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

[keio-audio.zip](https://github.com/user-attachments/files/21008737/keio-audio.zip)

birdybro, 2025-07-02:
@RetroShopPT Thank you for offering to look into this. Good luck with the busy schedule.

When you do check it out, can you confirm that the PLL to the PCM5102 DAC is stable/reliable? Switching the OSD on and off, turning on and off composite blend, changing these vga mode options, etc... This stuff might make the output pll unstable to the DAC maybe? Or maybe some kind of coupling from the video path is making it's way out the output ports alongside the audio. I'm not sure, just throwing some stuff out there. It really seems like some kind of interference from the digital domain on the board is making it's way up the gpio.

nekrondev, 2025-07-02:
> I wouldn't use Taki's mister.ini - not sure what they have changed. Grab this one: https://github.com/MiSTer-devel/Main_MiSTer/blob/master/MiSTer.ini and test again if you have a chance.

For the record: I added the devel mister.ini as an alternative config setting and tested again with Keio (US, CHD from SD card), but found no crackling noise.

birdybro, 2025-07-02:
@sorgelig two users now said that the test build I did with an updated framework solved the issue. @dshadoff suggested this test.

https://github.com/MiSTer-devel/MegaCD_MiSTer/compare/master...birdybro:updatesys

Could any of the following be responsible?

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

AtelierBleu, 2025-07-02:
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

I do get crackly audio even without anything attached to the VGA port.

TheJesusFish, 2025-07-03:
Best path forward is to wait for Ricardo and then (assuming his testing comes back normal) and then close this issue? I know the discord will love that SRG has another core to work on instead of 3DO :D

TheJesusFish, 2025-08-13:
Closing this as it seems to be metastability. MegaCD unstable doesn't show the issue and the released PSX core is also fine.

RetroShopPT, 2025-08-13:
I’ll only be able to finish the tests in about two weeks. Unfortunately, a family member passed away, so I’m running behind on everything, and then we have the holiday break. Still, I’ll be available to help in any way I can and run tests with several boards. Best regards to everyone.

Ricardo

psoma, 2025-09-05:
Only bought a CRT recently (was using digital/HDMI prior) and noticed this issue on Sonic CD, particularly during the intro which led me here.

Have a taki Mister Pi with 9.2 IO and outputting ypbpr.

Using https://github.com/birdybro/MegaCD_MiSTer/raw/refs/heads/updatesys/releases/MegaCD_20250701.rbf reduces the clicking/popping during the FMV portion of the intro, but it is still definitely present.

Experienced the same with the PSX core but was pointed to an updated rbf that completely addressed the issue.

To reiterate, the 20250701 build improves the issue, but certainly doesn’t eliminate it fully.

TheJesusFish, 2025-09-06:
@psoma Please try the unstable: https://github.com/MiSTer-unstable-nightlies/MegaCD_MiSTer/releases/download/unstable-builds/MegaCD_unstable_20250703_077d86.rbf

jotego, 2025-10-06:
Was the culprit for this identified? Is it some timing issue in the core compilation or is it a hardware problem on the board itself?

TheJesusFish, 2025-10-06:
> Was the culprit for this identified? Is it some timing issue in the core compilation or is it a hardware problem on the board itself?

It was not. @RetroShopPT was going to take a look but real life has not been kind to them so I don't think they have had a chance to look.

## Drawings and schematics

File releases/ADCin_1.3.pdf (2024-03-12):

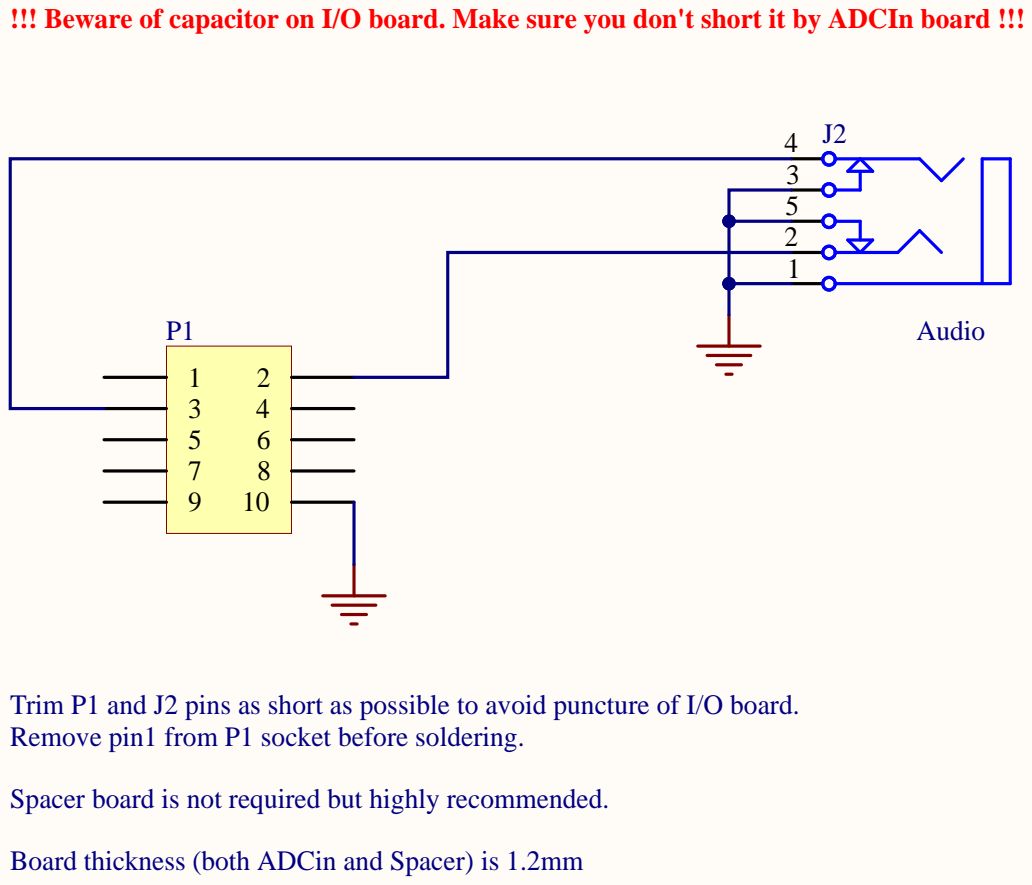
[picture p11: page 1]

!!! Beware of capacitor on I/O board. Make sure you don't short it by ADCIn board !!!

Trim P1 and J2 pins as short as possible to avoid puncture of I/O board.
Remove pin1 from P1 socket before soldering.

Spacer board is not required but highly recommended.

Board thickness (both ADCin and Spacer) is 1.2mm

ADC input board for MiSTer

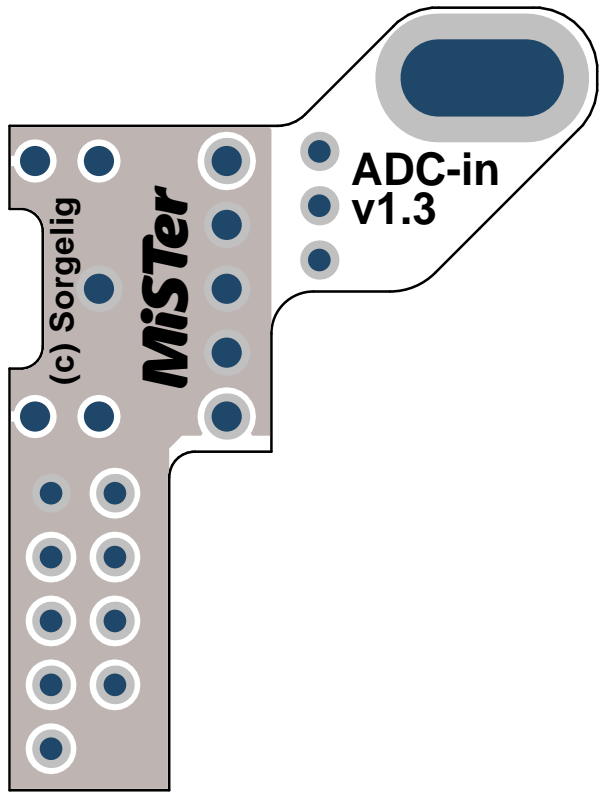
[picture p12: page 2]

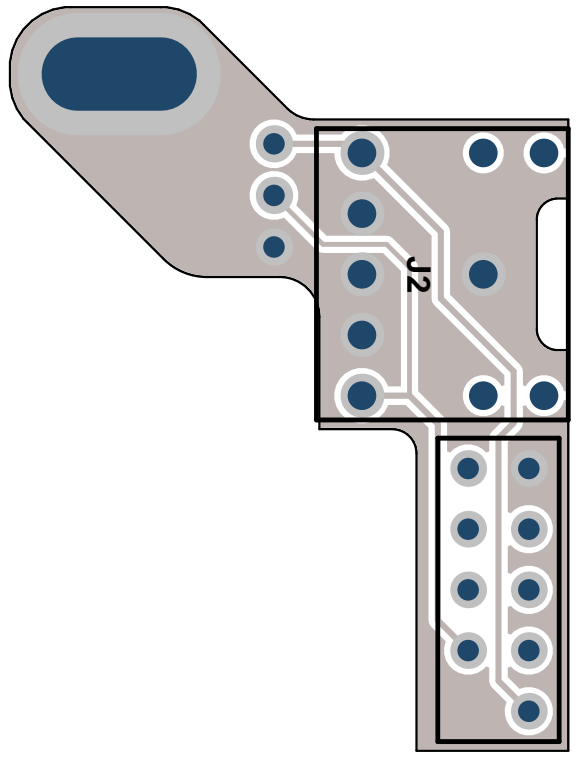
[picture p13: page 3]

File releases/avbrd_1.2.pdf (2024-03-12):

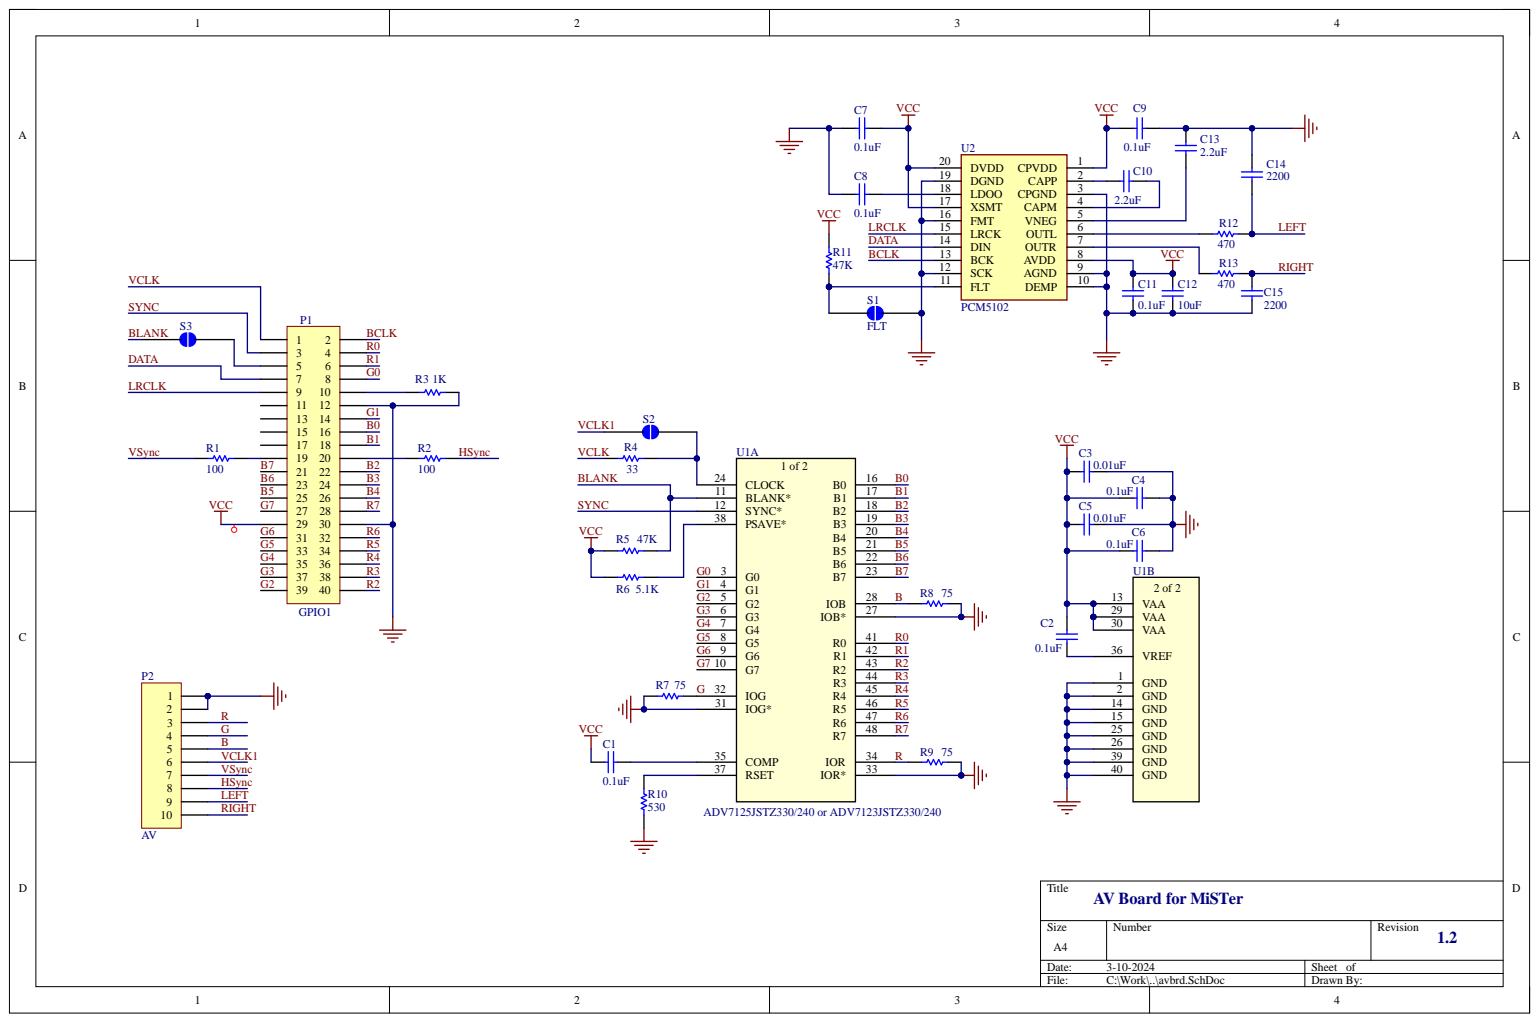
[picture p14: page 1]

DGND 19 | 2 | | C10
LDOO 18 | 3
XSMT 17 | 4
FMT 16 | 5
LRCK 15 | 6 7

BCK 13 | 8
SCK 12 | 9

AV Board for MiSTer

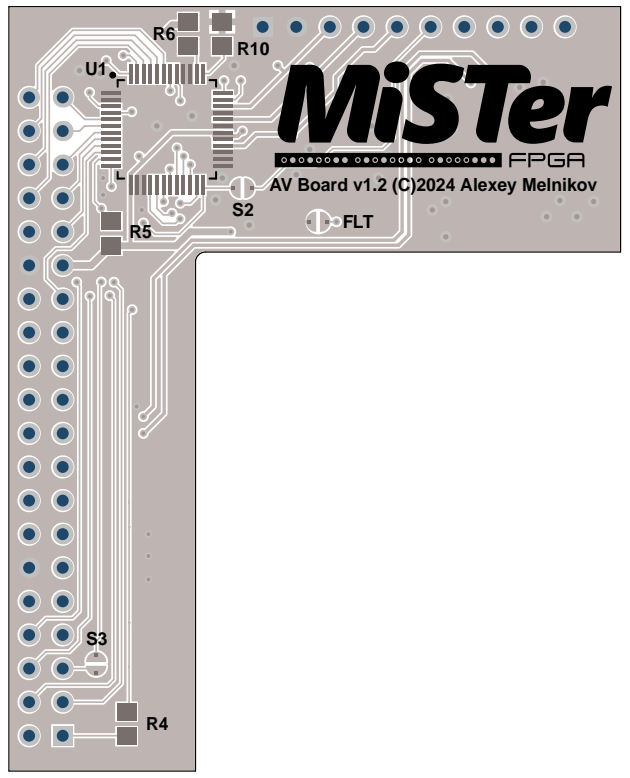
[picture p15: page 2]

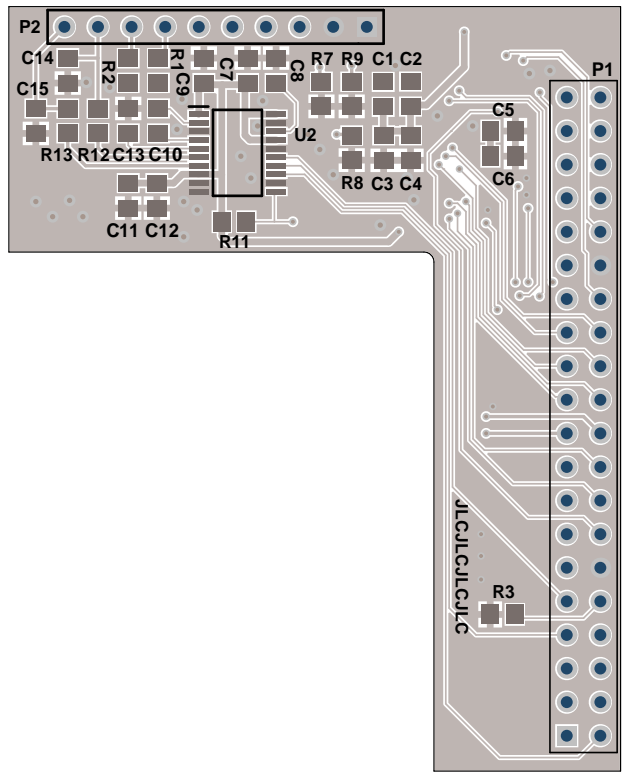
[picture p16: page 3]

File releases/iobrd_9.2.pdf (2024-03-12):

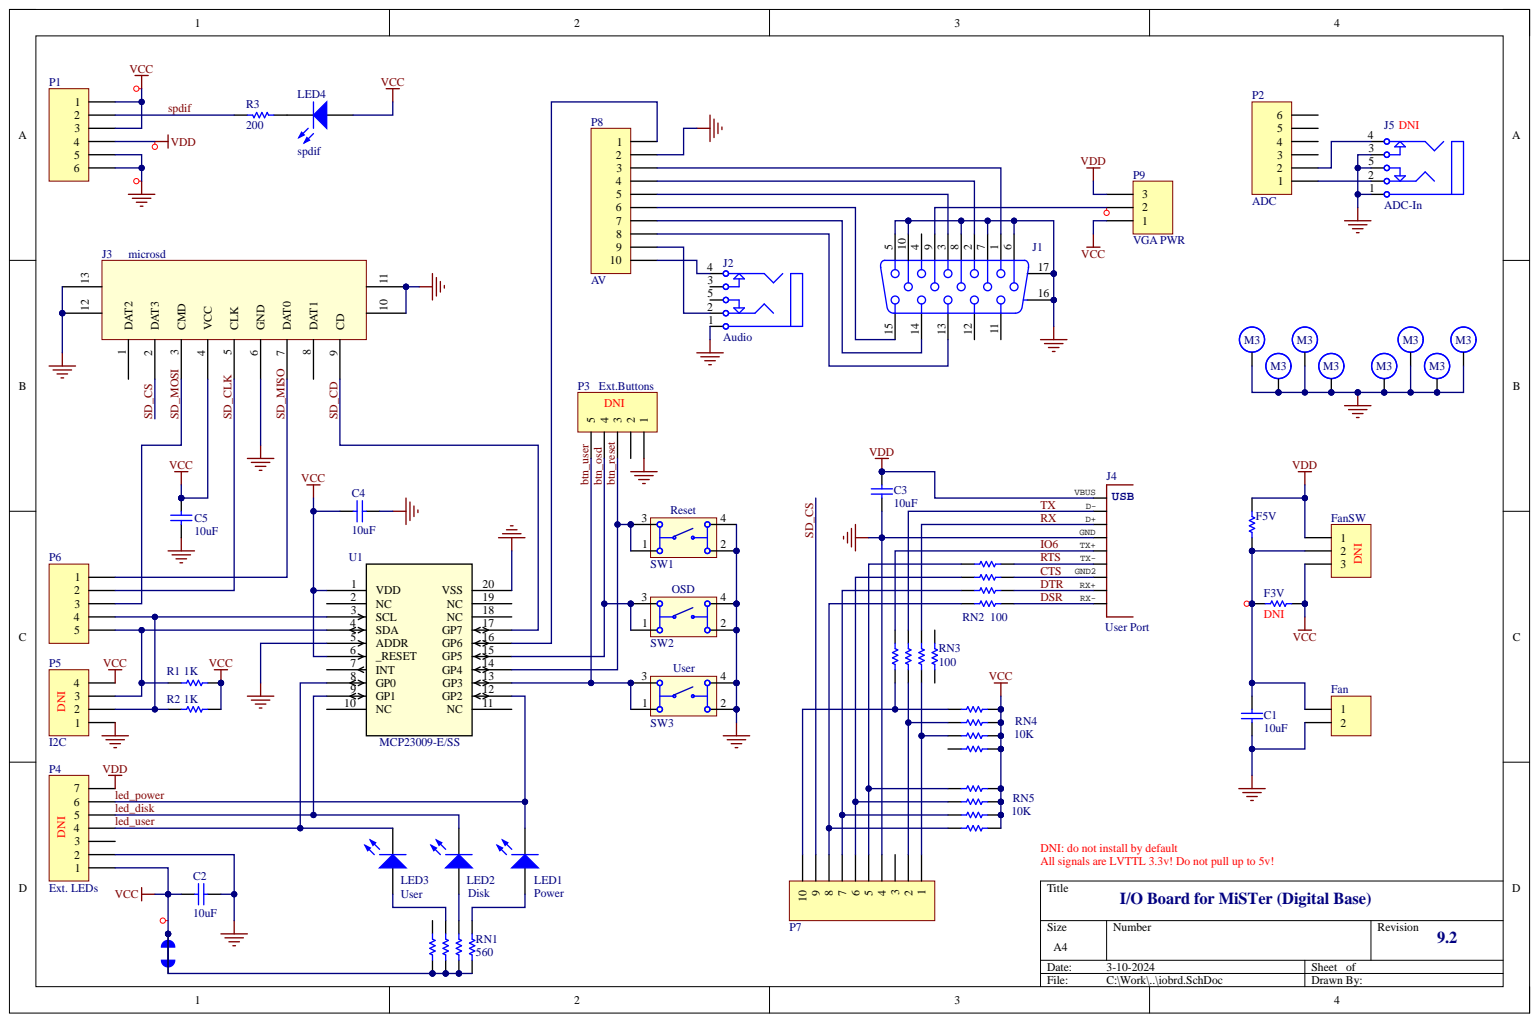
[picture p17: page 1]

VCC

SDA 4

_RESET 6

led_disk
led_user

DNI: do not install by default
All signals are LVTTL 3.3v! Do not pull up to 5v!

I/O Board for MiSTer (Digital Base)

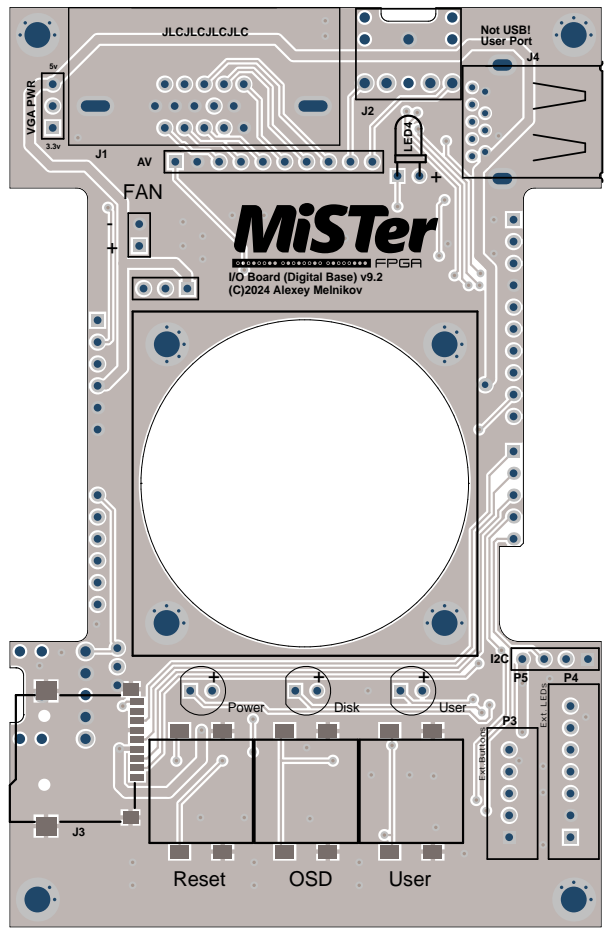
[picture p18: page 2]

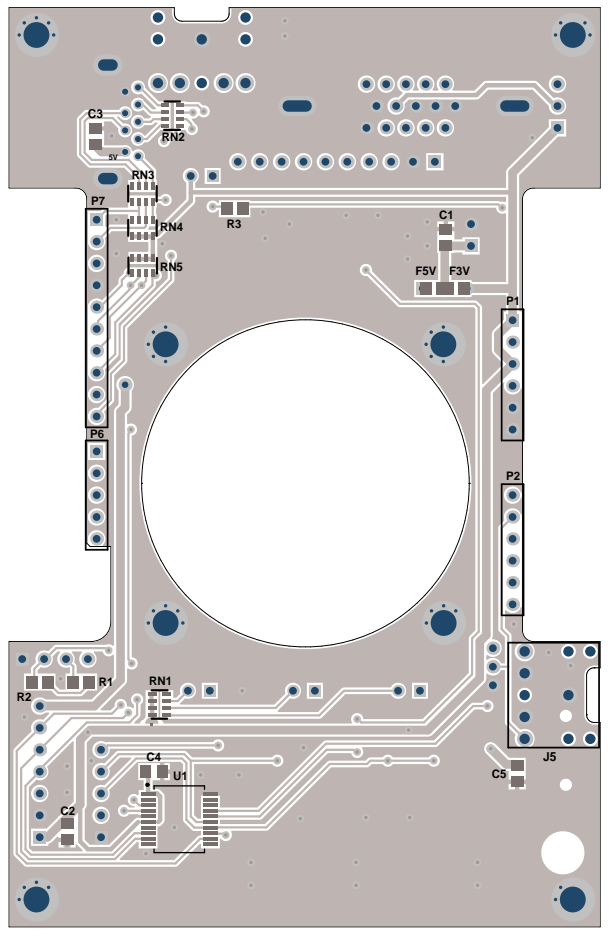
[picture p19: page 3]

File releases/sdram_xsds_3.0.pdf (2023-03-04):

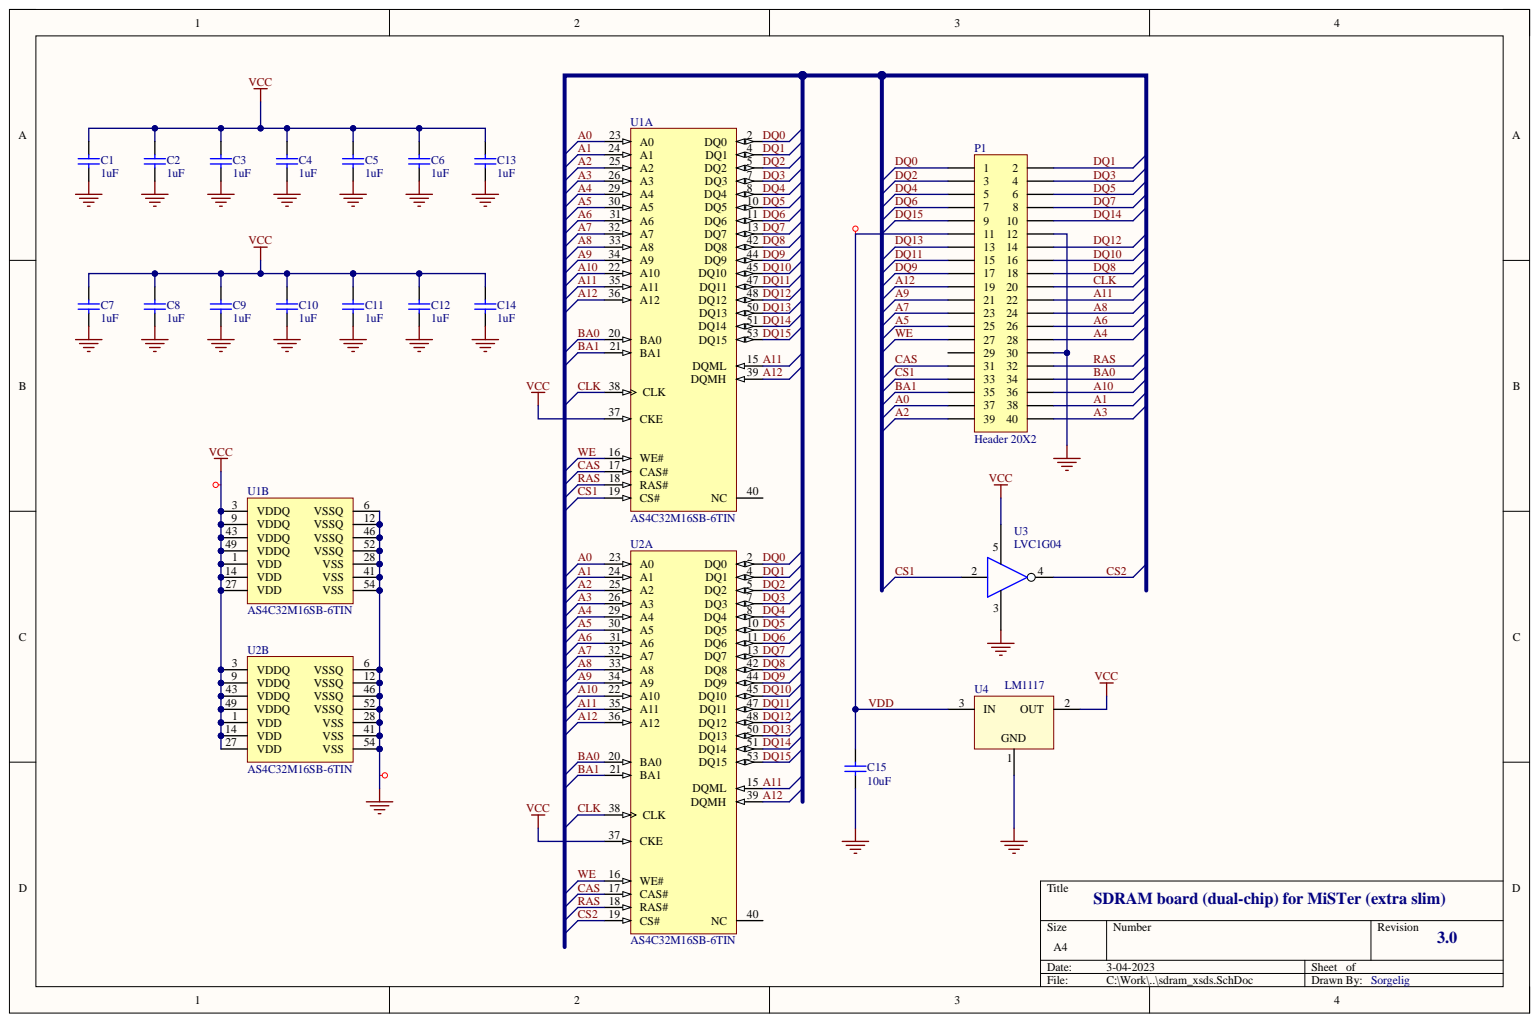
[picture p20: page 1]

SDRAM board (dual-chip) for MiSTer (extra slim)

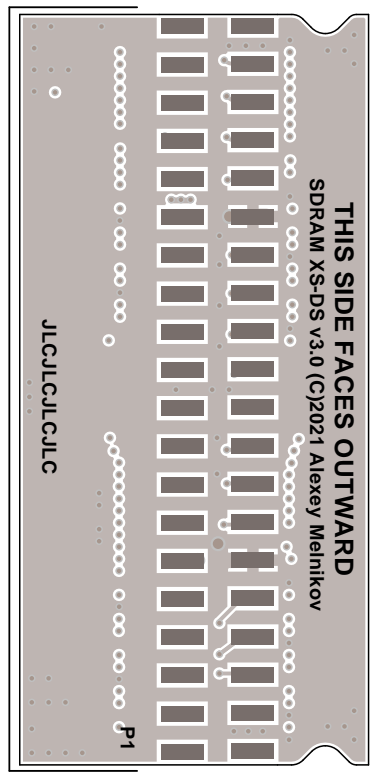
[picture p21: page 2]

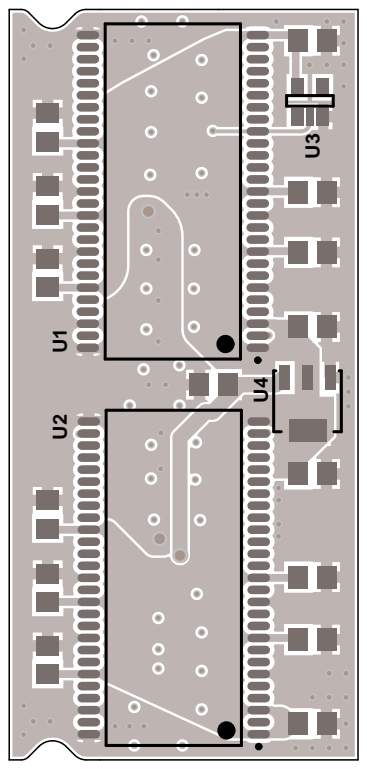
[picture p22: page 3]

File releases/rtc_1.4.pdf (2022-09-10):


MOSI
MISO
SCK

B1, B1a: Only one battery should be installed.



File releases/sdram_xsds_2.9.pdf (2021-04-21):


SDRAM board (dual-chip)



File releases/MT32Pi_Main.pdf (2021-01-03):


DNI - do not install (future/optional feature)



MT32-pi interface board v2.1 (C) 2020 Alexey Melnikov

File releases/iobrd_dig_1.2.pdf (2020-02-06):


Reset | RTS

MCP23009-E/SS

NOTE: SW[3] on DE10-Nano must be in ON position to enable this board!

led_disk
led_user

DNI: do not install by default
All signals are LVTTL 3.3v! Do not pull up to 5v!

Digital I/O Board for MiSTer



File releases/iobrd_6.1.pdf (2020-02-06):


RX
TX
RTS | SOG
CTS

JP3V | | DAT3

VDD | CMD

CLK

DNI: do not install by default

RN1-RN11: tolerance 1%. Tested with: R=240, 2R=475 ~AND~ R=300, 2R=604

Other R/2R combinations are possible M3

Override 6 | | J1 17

P5 (on-board LEDs): closed - ON, opened - OFF
P8 (VGA Power): 1-2 - 3.3V, 2-3 - 5V, opened - OFF
All signals are LVTTL 3.3v! Do not pull up to 5v!

VSync



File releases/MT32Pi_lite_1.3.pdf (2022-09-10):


DNI - do not install (future/optional feature)



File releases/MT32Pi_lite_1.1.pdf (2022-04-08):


DNI - do not install (future/optional feature)



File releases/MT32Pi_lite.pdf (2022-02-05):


DNI - do not install (future/optional feature)



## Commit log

2017-06-28 Initial commit.
    [Schlib1.SchLib, footprints.PcbLib, iobrd.PcbDoc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]
2017-06-28 I/O Board v2.6.
    [iobrd.PcbDoc]
2017-06-28 Update capacitor values on SDRAM board.
    [sdram.PcbDoc, sdram.SchDoc]
2017-06-28 Add PDF outputs. Small corrections.
    [iobrd.PcbDoc, iobrd.PrjPcb, iobrd.SchDoc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]
2017-07-01 Add SDRAM reversed design.
    [iobrd.PrjPcb, sdram_rev.PcbDoc, sdram_rev.PrjPcb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]
2017-07-05 IO Board: add Ext.VGA connector.
    [iobrd.PcbDoc, iobrd.SchDoc]
2017-07-10 IOBoard: Adjust R1,R7,R13 values. Release v2.7 gerber and PDF.
    [iobrd.SchDoc]
2017-07-20 SDRAM v3.1U and rev v3.2.
    [iobrd.PrjPcb, sdram.PcbDoc, sdram.SchDoc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]
2017-08-07 Use classic VGA connector on I/O Board.
    [footprints.PcbLib, iobrd.PcbDoc, iobrd.PrjPcb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]
2017-08-07 Some adjustments in I/O Board PCB.
    [iobrd.PcbDoc, iobrd.SchDoc]
2017-09-05 I/O Board v4.1
    [Schlib1.SchLib, footprints.PcbLib, iobrd.PcbDoc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]
2017-09-06 Remove SDRAM_rev.
    [sdram_rev.PcbDoc, sdram_rev.PrjPcb, sdram_rev.SchDoc]
2017-09-10 Refactor and update libraries.
    [Schlib1.SchLib, footprints.PcbLib, iobrd.PrjPcb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]
2017-09-10 SDRAM_uni v3.2U: Minor updates.
    [sdram_uni.PcbDoc, sdram_uni.SchDoc]
2017-09-10 RTC v1.0
    [rtc.PcbDoc, rtc.PrjPcb, rtc.SchDoc]
2017-09-10 I/O Board v5.1
    [iobrd.PcbDoc, iobrd.SchDoc]
2017-09-11 Update the boards with more 3D models.
    [iobrd.SchDoc, lib.PcbLib, lib.SchLib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]
2017-09-13 I/O Board v5.1 release files.
    [iobrd.SchDoc]
2017-09-17 I/O Board v5.1 pdf update.
    [iobrd.PrjPcb]
2017-09-17 Update Library.
    [lib.PcbLib, lib.SchLib]
2017-09-17 MBModel: visual test model for expansion boards and case design.
    [mb.PrjPcb]
2017-09-17 SDRAM: update 3-pin connector height in 3D model.
    [sdram_uni.PcbDoc]
2017-09-17 RTC v1.2
    [rtc.PcbDoc, rtc.PrjPcb, rtc.SchDoc]
2017-09-17 I/O Board v5.2
    [iobrd.PrjPcb, iobrd.SchDoc]
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2017-09-18 Release files for I/O Board v5.2 and RTC v1.2
    [iobrd.PrjPcb]
2017-09-22 Update annotations for RTC.
    [rtc.PcbDoc, rtc.SchDoc]
2017-09-22 RTC: add battery holders part numbers.
    [rtc.SchDoc]
2017-12-21 Extra slim SDRAM v1.1.
    [sdram_xs.PcbDoc, sdram_xs.PrjPcb, sdram_xs.SchDoc]
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2018-03-03 RTC v1.3: add I2C/SPI header and temperature sensor.
    [lib.SchLib, rtc.PcbDoc, rtc.SchDoc]
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2018-03-03 Add SDRAM_SRAM board. Experimental and not supported. Not for production.
    [sdram_sram.PcbDoc, sdram_sram.PrjPcb, sdram_sram.SchDoc]
2018-03-03 Add PiTop adoptation boards.
    [PiTopAIO.PrjPcb, PiTopAudio.PrjPcb, PiTopConn.PcbDoc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]
2018-03-03 Rename release folder. Add outjob files. Update all PDF files with better PCB pictures.
    [sdram_uni.PcbDoc, sdram_uni.PrjPcb, sdram_uni.SchDoc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]
2018-03-06 PiTopAudio,PiTopAIO: modify MAX98357A solder mask to relax manufacturing requirements.
    [PiTopAIO.PrjPcb, audio.SchDoc, io.SchDoc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]
2018-03-06 RTC: correct U2 part numbers.
    [rtc.SchDoc]
2018-03-14 Drop PiTopConn.
    [PiTopConn.PcbDoc, PiTopConn.PrjPcb, PiTopConn.SchDoc]
2018-03-14 PiTopAudio: minor adjustment.
    [serial.SchDoc]
2018-03-14 Release PiTopUSBHub v1.1
    [PiTopUSBHub.PrjPcb, PiTopUSBHub.SchDoc]
2018-03-21 PiTopUSBHub v2 and v3.
    [PiTopUSBHub.PrjPcb, PiTopUSBHub.SchDoc, PiTopUSBHub_UB.SchDoc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]
2018-03-27 Library update.
    [lib.SchLib]
2018-03-27 USBHub v1.0.
    [USBHub.PrjPcb, USBHub.SchDoc]
2018-03-27 I/O Board: add I2S connector. Connect P5 internally. Add notes which connectors should not be installed by default.
    [iobrd.PrjPcb, iobrd.SchDoc]
2018-03-27 Small cleanup.
    [iobrd.PrjPcb]
2018-05-24 iobrd update.
    [iobrd.PrjPcb, iobrd.SchDoc]
2018-05-28 iobrd: add serial connector (preliminary).
    [iobrd.PrjPcb, iobrd.SchDoc]
2018-06-11 Update libraries.
    [lib.SchLib]
2018-06-11 I/O Board v5.5
    [iobrd.PrjPcb, iobrd.SchDoc]
2018-06-11 USBHub v1.1
    [USBHub.PrjPcb, USBHub.SchDoc]
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2019-03-01 I/O Board v5.6.
    [iobrd.PrjPcb, iobrd.SchDoc]
2019-03-06 Update the library.
    [lib.SchLib]
2019-03-06 USB Hub v1.2.
    [USBBridge.PcbDoc, USBBridge.PrjPcb, USBBridge.SchDoc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]
2019-03-11 Update USBHub annotations in schematics.
    [USBHub.SchDoc]
2019-04-01 Add USBBracket and USBBridge3150 boards.
    [USBBracket.PcbDoc, USBBracket.PrjPcb, USBBracket.SchDoc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]
2019-04-01 IOBoard: fullsized version as a main version.
    [iobrd.SchDoc]
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2019-04-20 Add ADCin, update USBBracket.
    [ADCin.PcbDoc, ADCin.PrjPcb, ADCin.SchDoc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]
2019-07-03 USBHub v2.1
    [USBHub.PcbDoc, USBHub.PrjPcb, USBHub.SchDoc]
2019-07-03 I/O Board v6.0
    [iobrd.PrjPcb, iobrd.SchDoc]
2019-07-03 Update libs.
    [lib.SchLib]
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2019-09-06 SDRAM: XS v2.2, XSD v2.4
    [lib.SchLib, sdram_xs.PcbDoc, sdram_xs.PrjPcb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]
2019-09-06 Fix SDRAM chip part number.
    [sdram_xsd.PcbDoc, sdram_xsd.SchDoc]
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2020-02-06 I/O Board v6.1, Digital I/O Board v1.2
    [iobrd.SchDoc, iobrd_dig.PrjPcb, iobrd_dig.SchDoc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]
2020-02-06 Add Note to Digital I/O Board.
    [iobrd_dig.SchDoc]
2021-01-03 Add MT32-pi interface board.
    [MT32Pi_Main.PrjPcb, MT32Pi_Main.SchDoc, MT32Pi_Top.PcbDoc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]
2021-04-21 Add SDRAM XSDS v2.9
    [sdram_xsds.PcbDoc, sdram_xsds.PrjPcb, sdram_xsds.SchDoc]
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2023-03-04 Add SDRAM XSDS v3.0
    [sdram_xsds.PcbDoc, sdram_xsds.PrjPcb, sdram_xsds.SchDoc]
2024-03-12 I/O Board 9.2, AVBoard 1.2, ADCin v1.3, removed obsolete boards.
    [ADCin.PcbDoc, ADCin.PrjPcb, ADCin.SchDoc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]
